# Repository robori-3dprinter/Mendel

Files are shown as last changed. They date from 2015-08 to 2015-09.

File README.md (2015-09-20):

# Robori Mendel

File master printer 3D Robori Mendel.

Full kit printer 3D Robori Mendel tersedia di :

http://www.robori.com/index.php?id_product=95&controller=product

Spesifikasi printer 3D Robori Mendel dan panduan merakit dapat dilihat di :

http://www.robori.com/documentation/Mendel

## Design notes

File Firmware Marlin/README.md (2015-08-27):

Firmware Marlin yang dikonfigurasi untuk printer 3D Robori Mendel.

Langkah-langkah meng-upload ke board Arduino Mega 2560 :
- Install Arduino versi 1.0.6 dari <a href="https://www.arduino.cc/en/Main/OldSoftwareReleases#previous">website Arduino</a>.
- Jalankan program Arduino dan buka file Marlin.ino yang terdapat di folder Marlin.
- Hubungkan board Arduino Mega ke komputer dengan kabel USB.
- Pilih menu Tools - Board - Arduino Mega 2560 or Mega ADK.
- Pilih menu Tools - Serial Port dan pilih port Arduino Mega yang didaftarkan sistem operasi saat menghubungkan board Arduino Mega ke komputer.
- Klik tombol Upload dan tunggu hingga proses compile dan upload selesai.

Firmware Marlin merupakan proyek open source dengan lisensi GPL. Versi asli dan terbaru dari firmware ini dapat didownload di :

https://github.com/MarlinFirmware

Dokumentasi firmware Marlin terdapat di :

http://www.marlinfirmware.org

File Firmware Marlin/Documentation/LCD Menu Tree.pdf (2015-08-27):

# Marlin LCD Menu Tree

Main Menu | Tune Menu | Move Menu
Info screen | Main | Prepare
Tune | Speed | Move 10mm | Move Menu
Prepare | Nozzle | Move 1mm | Move axis
Control | Nozzle2 | Move 0.1mm | Move X
Pause print | Nozzle3 | | Move Y
Resume print | Bed | | Move Z
Stop print | Fan speed | Temperature Menu | Extruder
Print from SD | Flow | Control
Change SD card | Babystep X | Nozzle
No SD card | Babystep Y | Nozzle2
Init. SD card | Babystep Z | Nozzle3
| Change filament | Bed
| | Fan speed
| | Autotemp
| Prepare Menu | \002 Min
| Main | \002 Max | Preheat PLA
| Autostart | \002 Fact | Temperature
| Disable steppers | PID-P | Fan speed
| Auto home | PID-I | Nozzle
| Preheat PLA | PID-D | Bed
| Preheat ABS | PID-C | Store memory
| Cooldown | Preheat PLA conf
| Switch power off | Preheat ABS conf | Preheat ABS
Switch power on | Temperature
Move axis | Fan speed
| Motion Menu | Nozzle
| Control | Bed
Control Menu | Z Offset | Store memory
Main | Accel
Temperature | Vxy-jerk
Motion | Vz-jerk
LCD contrast | Ve-jerk
Retract | Vmax x
Store memory | Vmax y
Load memory | Vmax z
Restore failsafe | Vmax e
| Vmin
| VTrav min
SD Card Menu | Amax x
Main | Amax y
Refresh | Amax z
filenames | Amax e
| A-retract
| Xsteps/mm
| Ysteps/mm
| Zsteps/mm
| Esteps/mm
| Endstop abort

Retract Menu
Control
AutoRetr.
Retract mm
Retract F
Hop mm
UnRet +mm
UnRet F

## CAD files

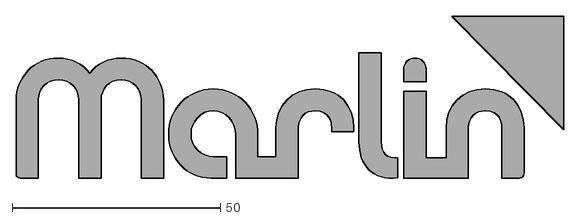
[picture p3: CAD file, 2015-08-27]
Firmware Marlin/Documentation/Logo/Marlin Logo.dxf
131.6 x 39.5

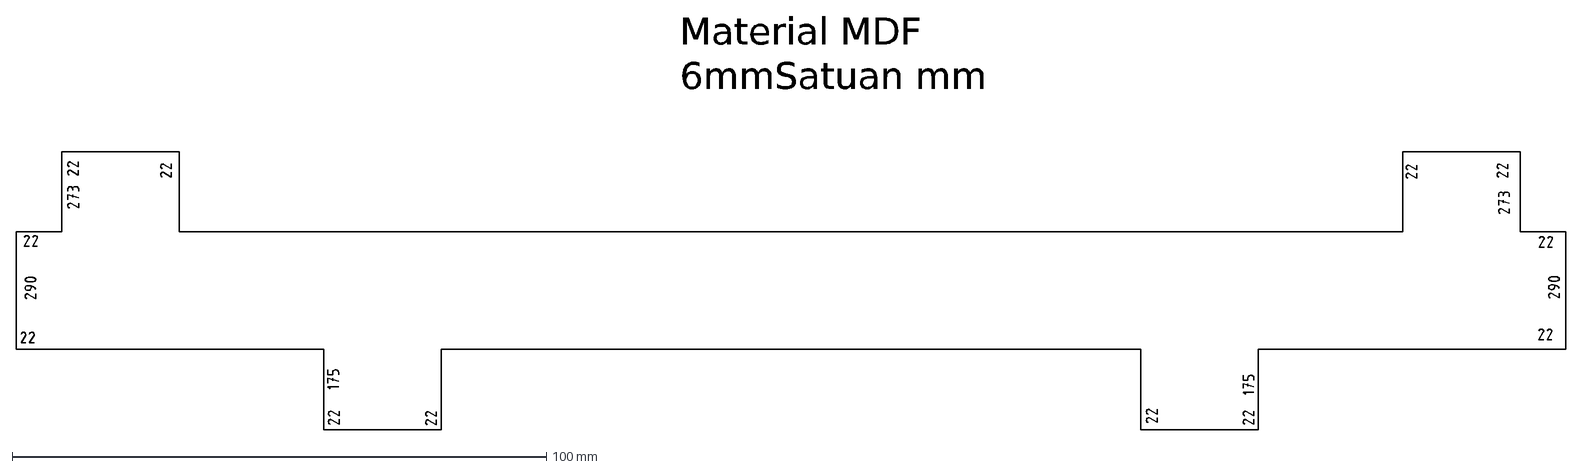
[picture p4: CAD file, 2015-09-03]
Lasercut Part/measuring-jig.dxf
Material MDF 6mm Satuan mm

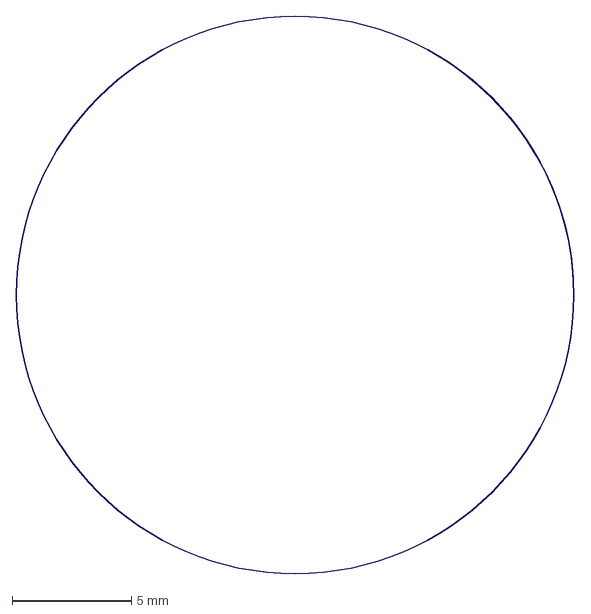
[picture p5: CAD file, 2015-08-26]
OpenSCAD/vertex-body-hole-qcad.dxf
23.4 x 23.4 mm

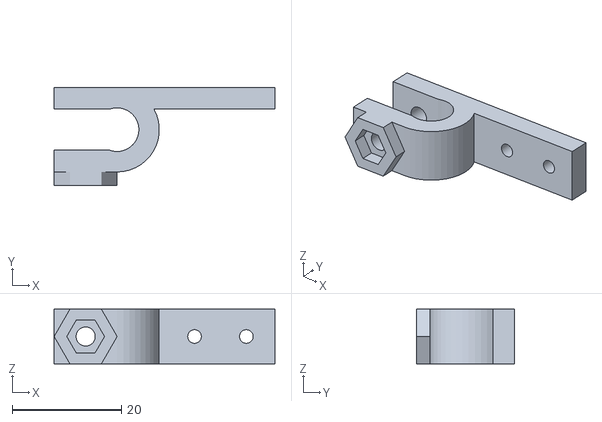
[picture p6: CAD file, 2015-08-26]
Printed Part/endstop-holder-3x.stl
40.5 x 18.0 x 10.0

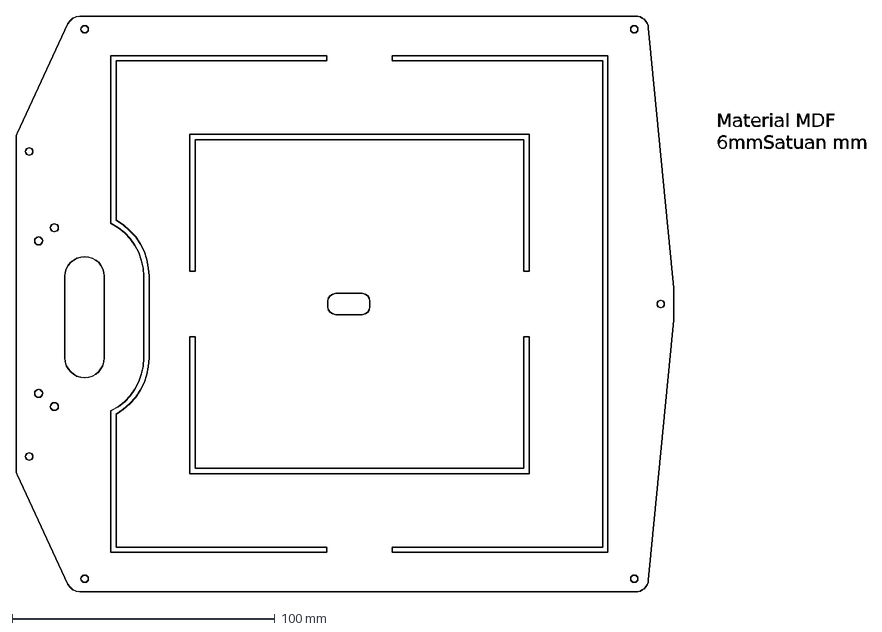
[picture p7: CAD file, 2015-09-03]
Lasercut Part/heat-bed-insulator.dxf
Material MDF 6mm Satuan mm

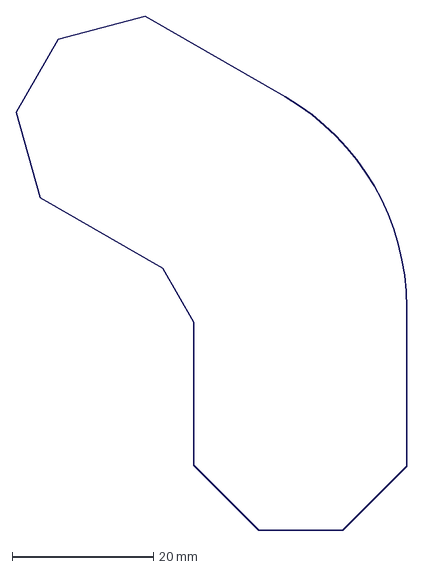
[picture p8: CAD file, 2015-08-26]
OpenSCAD/vertex-body-fixed-qcad.dxf
55.4 x 72.9 mm

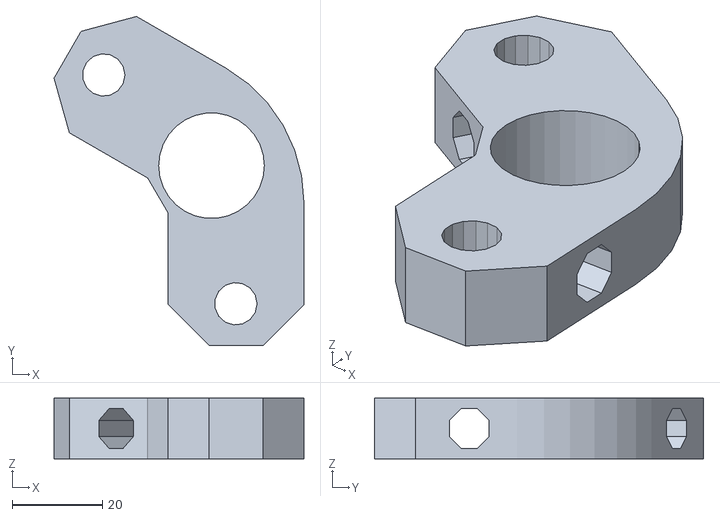
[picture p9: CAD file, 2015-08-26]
Printed Part/frame-vertex-2x.stl
55.4 x 72.9 x 13.5

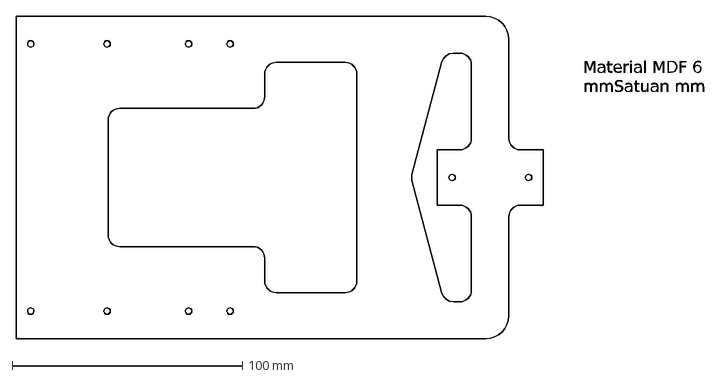
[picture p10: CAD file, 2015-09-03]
Lasercut Part/y-carriage.dxf
Material MDF 6 mm Satuan mm

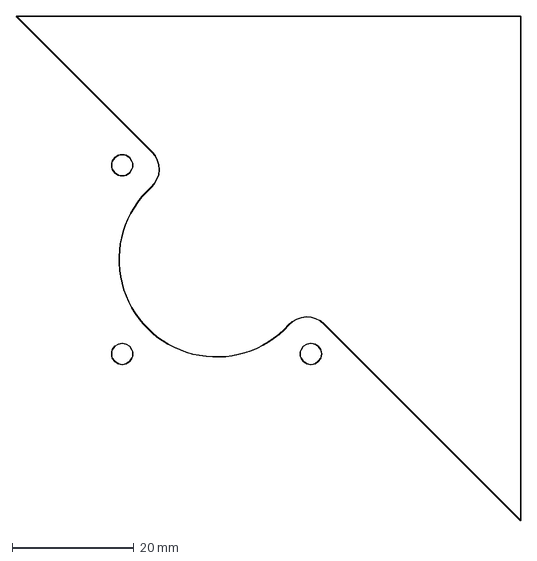
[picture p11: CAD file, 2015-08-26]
OpenSCAD/x-motor-cutout.dxf
82.9 x 82.9 mm

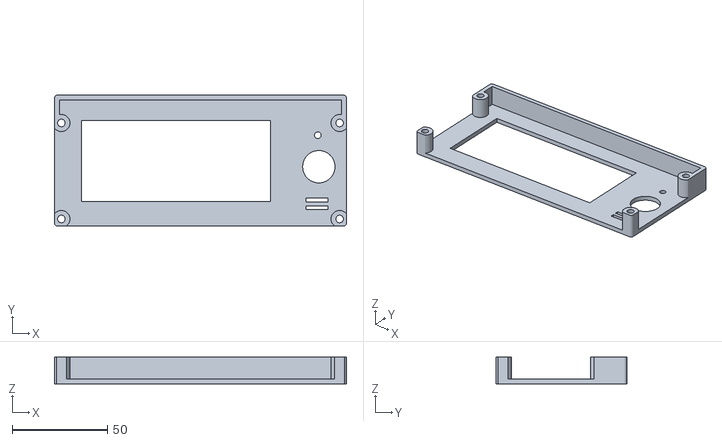
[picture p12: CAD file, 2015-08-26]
Printed Part/lcd-cover-1x.stl
153.0 x 68.5 x 14.0

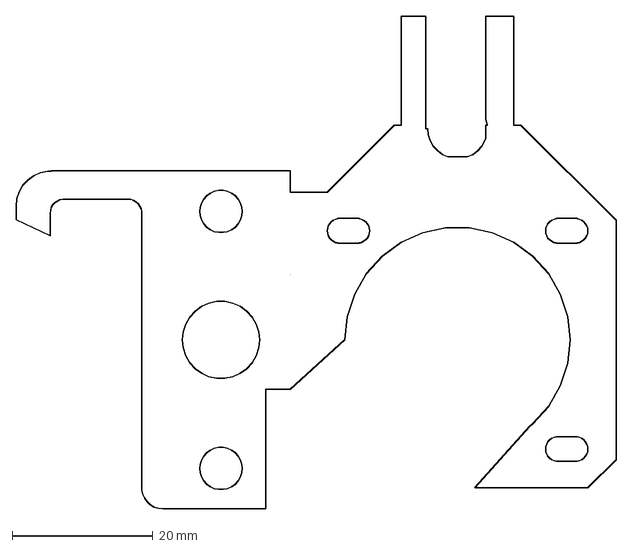
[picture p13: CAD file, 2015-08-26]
OpenSCAD/extruder-block-projection.dxf
85.2 x 70.0 mm

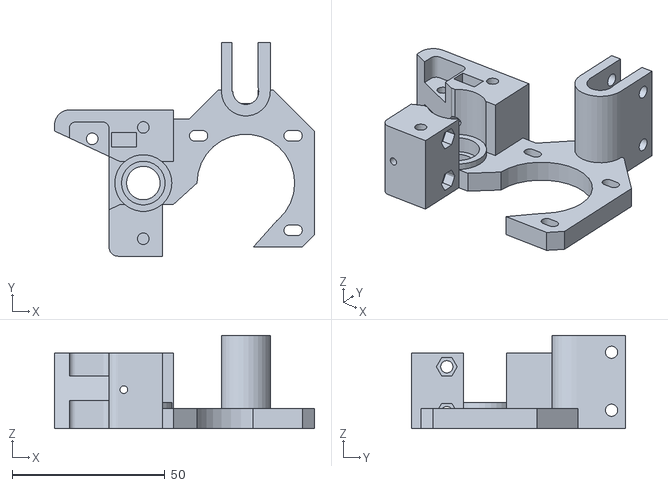
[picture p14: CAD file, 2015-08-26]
Printed Part/extruder-block-1x.stl
85.2 x 70.0 x 30.5

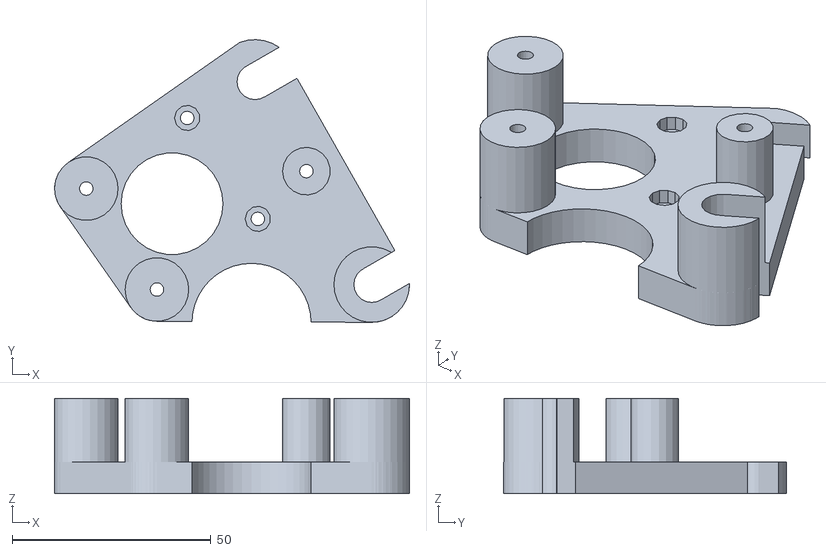
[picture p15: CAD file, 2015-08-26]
OpenSCAD/reprappro-y-motor-mount-1off.stl
89.3 x 71.2 x 24.0

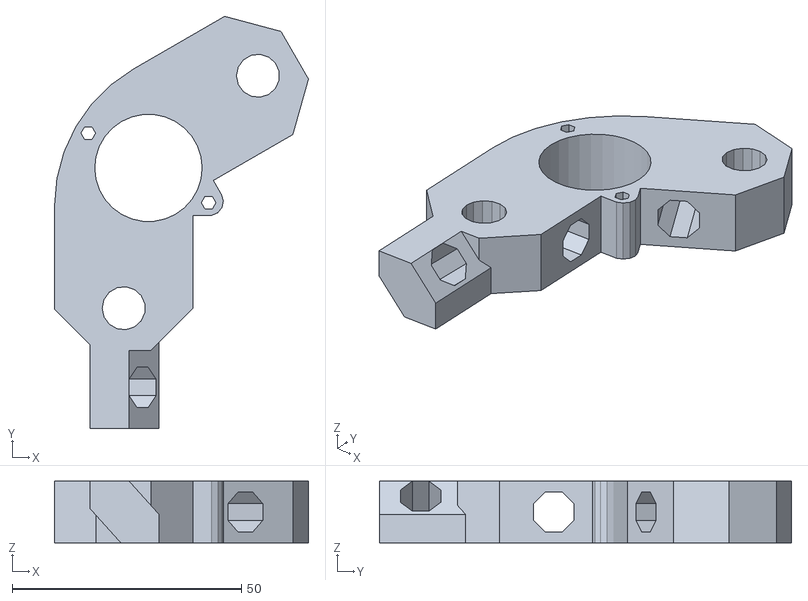
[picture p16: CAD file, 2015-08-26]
Printed Part/frame-vertex-foot-right-2x.stl
55.4 x 89.9 x 13.5

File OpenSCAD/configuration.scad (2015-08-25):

// PRUSA Mendel  
// Configuration file
// GNU GPL v2
// Josef Pra
// josefprusa@me.com
// prusadjs.cz
// http://www.reprap.org/wiki/Prusa_Mendel
// http://github.com/prusajr/PrusaMendel


// PLEASE SELECT ONE OF THE CONFIGURATIONS BELOW
// BY UN-COMMENTING IT


variant=0; //0 for metric
//variant=1; //1 for SAE
if(variant==0){
echo("variant: metric");
}else if(variant==1){
echo("variant: sae");
} else{
echo("WARNING: INVALID CONFIGURATION");
}




vars=[
//[m8_dia,m8_nut, m4_dia, m4_nut, m3_dia, m3_nut, bush_dia, mot_shaft, bush_rod, bush_outerdia, bush_length, m5_dia, m5_nut]
[9, 16.4, 5,9, 3.4, 6.5, 11, 5.3, 8, 16, 11, 5.6, 10],//metric - M3 nut was 7; M3 was 4.4
[9,15.7,5.5,10.6,5.5,10.6,11.5,5.3,7.9375,16,11,5.6, 10]//SAE
];


//BUSHING TYPE Can generate three versions
// 1 - regular old ones
// 2 - helical ones
// 3 - holders for brass or any other bought bushings
bushing_type = 2;


//Round corner diameter
round_corner_diameter = 5;		// Original = 8


//Thin wall size
layer_height = 0.4;
perimeter_width_over_thicknes = 1.6;
infill_widht_over_thickness = 1.55;
thin_wall = 2*(perimeter_width_over_thicknes*layer_height+infill_widht_over_thickness*layer_height);
if(thin_wall<2){
	echo("Check thin wall size, its below 2mm!");
}
echo(thin_wall);


//DO NOT TOUCH THIS SECTION!
m8_diameter = vars[variant][0];
m8_nut_diameter = vars[variant][1];
m4_diameter = vars[variant][2];
m4_nut_diameter = vars[variant][3];
m3_diameter = vars[variant][4];
m3_nut_diameter = vars[variant][5];
bushing_diameter = vars[variant][6];
motor_shaft=vars[variant][7];
bushing_rodsize = vars[variant][8];
bushing_outerDiameter = vars[variant][9];
bushing_lenght = vars[variant][10];
m5_diameter = vars[variant][11];
m5_nut_diameter = vars[variant][12];



// MINI-HUXLEY VERSION (TODO, just place holder)
// include <configuration-huxley.scad>


// MEGA VERSION (TODO, just place holder)
// include <configuration-mega.scad>

// Robori Mendel
include <x-axis-data.scad>

// Gap between the X rods

//x_rod_centres=70;			// Prusa Mendel
x_rod_centres=rod_dist;		// Robori Mendel
y_rod_centres=183;
belt_width=6;
belt_clamp_centres=18;
ptfe_diameter=4;
z_slot_width=3.5;

vertex_x_rod_1=[11.013,59.912];
vertex_x_rod_2=[40.274,9.249,0];
vertex_x_rod_gap=sqrt((vertex_x_rod_1.x-vertex_x_rod_2.x)*(vertex_x_rod_1.x-vertex_x_rod_2.x) +(vertex_x_rod_1.y-vertex_x_rod_2.y)*(vertex_x_rod_1.y-vertex_x_rod_2.y) );

// Some basic functions, probably should be somewhere else
module roundcorner(diameter){
	difference(){
		cube(size = [diameter,diameter,99], center = false);
		translate(v = [diameter, diameter, 0]) cylinder(h = 100, r=diameter, center=true);
	}
}

include <functions.scad>

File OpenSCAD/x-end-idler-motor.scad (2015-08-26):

// PRUSA Mendel  
// X-end with idler mount
// GNU GPL v2
// Josef Pra
// josefprusa@me.com
// prusadjs.cz
// http://www.reprap.org/wiki/Prusa_Mendel
// http://github.com/prusajr/PrusaMendel

include <configuration.scad>
include <bearing-mount-include.scad>
include <library/library_3d.scad>

lib3d_fn = 25;
$fn = 25;

// Modified by Adrian to remove bridges and to add a conical cavity for the bottom nut; this
// prints more cleanly and reliably.  26 May 2011

// Modified by Adrian to use an M5 nut drive, linear bearings, friction clamps rather than screw clamps, 
// And to generate both the motor and idler ends
// 9 Feb 2012

// 30 Jan 2015
// Modified by Neuro (Robori.com)
// - Prusa i3 style LM8UU bearing holder
// - New idler bearing holder with M5 screw hole for 605 bearing
// - Change rod centers to 65mm (default 70mm)
// - Make bigger void

// Print 1 of the objects generated when this is true, and one when it is false.
motor=true;

// Set this false for Igus bearings, true for LM8UUs
lm8uu=true;

// Show / hide rod centers
scaffold=false;

corection = 1.17; 
back_clamp=[-x_rod_centres/2, -5, 0];
front_clamp=[x_rod_centres/2, -5, 0];
z_adjust_radius=21;		// Original = 31.6
z_adjust_angle=80;			// Original = 45


module clamp()
{
	translate(v=[1, 0, 9]) difference()
	{
		translate(v=[1, 0, -3.5]) cube(size=[10, 29, 7], center=true);
		rotate([90, 0, 0]) cylinder(h=38, r=m8_diameter/2, $fn=20, center=true);
		translate([-1, -15, 0.5]) rotate([30, 0, 0]) cube([20, 20, 10], center=true);
		translate([-1, 15, 0.5]) rotate([-30, 0, 0]) cube([20, 20, 10], center=true);
	}
}

module clamp_gap()
{
	difference()
	{
		translate(v=[0, 0, 0]) cube(size=[6, 30, 15], center=true);
		translate(v=[1, 0, 0]) cube(size=[6, 28, 20], center=true);
	}
}

module xend_i()
{
	difference()
	{
		union()
		{
			if(motor)
			{
				// Block the ends
				translate(v = [-x_rod_centres/2+0.5, 13, 8])cube(size = [10,4,13], center = true);
				translate(v = [x_rod_centres/2-0.5, 13, 8])cube(size = [10,4,13], center = true);
			}
			else
			{
				// End adjust
				difference()
				{
					union()
					{
						translate(v = [-x_rod_centres/2, 18, 6.5])cube(size = [17,14,13], center = true);
						translate(v = [x_rod_centres/2, 18, 6.5])cube(size = [17,14,13], center = true);
					}
					translate(v = [-x_rod_centres/2, 13, 6.5])cube(size = [9,14,23], center = true);
					translate(v = [x_rod_centres/2, 13, 6.5])cube(size = [9,14,23], center = true);
					//Adjustment screws
					translate(v = [-x_rod_centres/2, 35, -16.7+24.5]) rotate(a=[90,0,0]) 
					{
						translate(v = [0, 0, 22]) cylinder(h = 42, r=1.7, $fn=20, center=true);
						translate(v = [0, 0, 17]) rotate(a=[0,0,30]) cylinder(h = 8, r=m3_nut_diameter/2, $fn=6, center=true);
					}
					translate(v = [x_rod_centres/2, 35, -16.7+24.5]) rotate(a=[90,0,0]) 
					{
						translate(v = [0, 0, 22]) cylinder(h = 42, r=1.5, $fn=20, center=true);
						translate(v = [0, 0, 17])   rotate(a=[0,0,30]) cylinder(h = 8, r=m3_nut_diameter/2, $fn=6, center=true);
					}
				}
			}

			// Rod centers
			if(scaffold)
			{
				translate(v = [0, -20, 0]) cylinder(h = 100, r=1, $fn=10, center=true);// Centre-marker screw drive
				translate(v = [0, 10, 0])cylinder(h = 100, r=1, $fn=30, center=true);// Centre-marker bearings
			}

			// The x rod clamps
			translate(back_clamp) clamp();
			translate(front_clamp) mirror([1,0,0]) clamp();

			difference()
			{
				translate(v = [0,35,24.5]) union()
				{
					difference()
					{
						// Rod block
						union()
						{
							translate(v = [-x_rod_centres/2+5, -40, -16.6])cube(size = [x_rod_centres/2-5,40,15.8], center = true);
							translate(v = [x_rod_centres/2-5, -40, -16.6])cube(size = [x_rod_centres/2-5,40,15.8], center = true);
						}
			
						//round corners
						translate(v = [x_rod_centres/2 + 10.1 - 1, -60.1, -25]) rotate(a=[0,0,90]) roundcorner(round_corner_diameter);
						translate(v = [x_rod_centres/2 + 10.1 - 1, -19.9, -25]) rotate(a=[0,0,-180]) roundcorner(round_corner_diameter);

						//holes for X axis
						translate(v = [-x_rod_centres/2, -18, -16.7]) rotate(a=[90,0,0])
						{
							translate(v = [0, 0, 22]) cylinder(h = 42, r=4.5, $fn=20, center=true);
							translate(v = [0, 2.60, 22]) rotate(a=[0,0,0]) cylinder(h = 42, r=3.65, $fn=6, center=true);
						}
						translate(v = [x_rod_centres/2, -18, -16.7]) rotate(a=[90,0,0])
						{
							translate(v = [0, 0, 22]) cylinder(h = 42, r=4.5, $fn=20, center=true);
							translate(v = [0, 2.60, 22]) rotate(a=[0,0,0]) cylinder(h = 42, r=3.65, $fn=6, center=true);
						}
			
						//slider cutouts --> ??
						translate(v = [0, -25, 15]) difference()
						{
							translate(v = [0, -0, -14.5])cube(size = [23,23,50], center = true);
						}
			
						//nut trap --> ??
						translate(v = [0, -55, 15])
						{
							difference()
							{
								translate(v = [0, -0, -15])cylinder(h = 50, r=m8_nut_diameter/2+thin_wall, $fn=6, center=true);
							}
						}
					}
			
					translate(v = [0, -25, 15]) difference()
					{
						union()
						{
							if(lm8uu)
							{
								// Disabled : replaced with Prusa i3 style LM8UU holder
								//translate(v = [0, -8, -7]) cube(size = [17+2*thin_wall,8, 65], center = true);
							}
							else
							{
								translate(v = [0, -8, -7]) cube(size = [17+2*thin_wall,8, 39], center = true);
							}
							translate(v = [0, -3.5, -31.6]) cube(size = [33,17,15.8], center = true);
						}
						translate(v = [0, 0, -17]) cube(size = [17,17, 105], center = true);
						translate(v = [0, 5, -31.6]) cube(size = [24,17,20], center = true);
					}
			
					// Bearing holders
					if(lm8uu)
					{
						// Disabled : replaced with Prusa i3 style LM8UU holder
						//translate([0,-34.5,-12.5]) rotate([-90,0,0]) bearing_holder(with_mountplate=false, vertical=true, slope=false,igus=!lm8uu);
						//translate([0,-34.5,28.5]) rotate([-90,0,0]) bearing_holder(with_mountplate=false, vertical=true, slope=true,igus=!lm8uu);
						// Prusa i3 LM8UU holder
						translate([0, -35 + 10, -24.5]) rotate([0, 0, 180]) prusa_i3_bearing_holder();
					}
					else
					{
						difference()
						{
							translate([0,-34.5,-24]) rotate([-90,0,0]) bearing_holder(with_mountplate=false, vertical=true, slope=false,igus=!lm8uu);
							translate([0,0,-49.5]) cube([100,100,50],center=true);
						}
						translate([0,-34.5,15.5]) rotate([-90,0,0]) bearing_holder(with_mountplate=false, vertical=true, slope=true,igus=!lm8uu);
					}
			
					//nut trap
					//correction for thin wall
					translate(v = [0, -55, 15])
					{
						difference()
						{
							union()
							{
								difference()
								{
									union()
									{
										translate(v = [0, -0, -19.5]) cylinder(h = 40, r=m5_nut_diameter/2+thin_wall*corection, $fn=6, center=true);
										translate(v = [0, 0, -31.6]) cube(size = [35,10,15.8], center = true);
									}
									cylinder(h = 90, r=m5_nut_diameter/2, $fn=6, center=true);
								}
					
								// Generate nut barrier with conical lead in under. 
								difference()
								{
									translate(v = [0, 0, -29]) cylinder(h = 16, r=m5_nut_diameter/2+thin_wall, $fn=6, center=true);
									translate(v = [0, 0, -32]) cylinder(h = 10, r1=10+2.5, r2=2.5, $fn=30, center=true);
									cylinder(h = 100, r=2.75, $fn=30, center=true);
								}
							}
							translate(v = [0, 0, 12.5]) cylinder(h = 90, r=m5_diameter/2, $fn=9, center=true);
						}
					}
			
					if(motor)
					{
						// Motor connector
						// x = motor body, y = motor center, z = motor center
						translate([0, -35, -24.5]) translate([-rod_dist/2 - belt_rod_dist + 0.75 + PULLEY_GT2_FLANGE_L + 5.5, 19.5 + 5 + NEMA17_L/2, 7.8 + belt_rod_h + 1.38 + PULLEY_GT2_TEETH_OD/2]) difference()
						{
							union()
							{
								translate([-6, -NEMA17_L/2 - 10, -NEMA17_L/2 - 5.68]) cube([6, NEMA17_L + 10, NEMA17_L + 5.68]);
								translate([-6, -30.5 - 4, -11.5]) cube([23.25 + 6, 4, 32.5]);
							}
							rotate([0,0,90]) rotate([90,0,0]) linear_extrude(file = "x-motor-cutout.dxf", layer = "0", height = 20, center = true, convexity = 10, twist = 0);
							translate([23.25, -30.5 - 6 - 1, -11.5 + 0.63]) rotate([0, -30, 0]) cube([30, 6 + 2, 40]);
						}
						/*** Disabled : Old motor connector
						difference()
						{
							//nema17 connector
							translate(v = [0, 3, -12]) mirror([1,0,0]) difference()
							{
								union()
								{
									translate(v = [x_rod_centres/2-4, -24.0, 20.5]) difference()
									{
										cube(size = [24,2,38], center = true); // Changed to a web
										translate(v = [-20, 0, 0]) rotate([0,15,0]) cube(size = [34,8,55], center = true);
									}
									translate(v = [x_rod_centres/2 + 7.5, 2, 13.5]) cube(size = [5,54,52], center = true);
									translate(v = [x_rod_centres/2 - 2.5, 2, -11]) cube(size = [20,54,3], center = true);
								}
								
								// some reduction of bottom part
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

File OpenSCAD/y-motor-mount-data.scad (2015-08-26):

// ========================================================================================
// Robori Mendel
// Shared modules for Y motor mount parts
// GNU GPL v3
//
// Contact : support@robori.com
// Reference : http://www.robori.com/documentation/Mendel
//
// History :
// 28 Jan 2015 - First version
// ========================================================================================

module belt_guide_bushing()
{
	// 2015-05-17 : increase height by 0.25mm
	linear_extrude(height=1 + 0.25 + 0.25, center=false, convexity=10) import(file="../dxf/y-motor-mount.dxf", layer="belt-guide-bushing-profile");
}

module bearing_bushing()
{
	bb_h = 3 + 0.25;
	bb_id = 5 + 0.5;
	bb_od1 = bb_id + 2*3;
	bb_od2 = bb_id + 2*1.5;
	
	difference()
	{
		cylinder(h=bb_h, r1=bb_od1/2, r2=bb_od2/2, center=false);
		translate([0, 0, -1]) cylinder(h=bb_h + 2, r=bb_id/2, center=false);
	}
}

// base h = 5
// bushing h = 16
module y_motor_mount_base()
{
	idler_d = 5 + 0.5;

	translate([0, 0, -3]) difference()
	{
		union()
		{
			// Original :
			//   base h = 8
			//   bushing h = 16
			import("reprappro-y-motor-mount-1off.stl");
			// Fill screw holes
			translate([-7, -25, 3]) cube([6, 6, 5]);
			translate([0, 17, 3]) cube([10, 10, 5]);
			translate([17, -8, 3]) cube([10, 10, 5]);
			translate([31, 5, 3]) cube([6, 6, 5]);
		}
		// Base h = 5
		translate([-35, -35, -1]) cube([100, 80, 3 + 1]);
		// Remove bushings
		translate([-30, -5, 8]) cube([20, 20, 16 + 1]);
		translate([-12, -30, 8]) cube([20, 20, 16 + 1]);
		translate([20, 0, 8]) cube([20, 20, 16 + 1]);
		// Motor screw slots
		translate([21.59, -3.81, 3 - 1]) rotate([0, 0, 53.77]) motor_screw_slot();
		translate([-21.59, 3.81, 3 - 1]) rotate([0, 0, 53.77]) motor_screw_slot();
		// Idler bearing screw hole
		translate([30.83, 10.02, 3 - 1]) cylinder(h=5 + 2, r=idler_d/2, center=false);
	}
}

module motor_screw_slot()
{
	base_h = 5;
	d = 3 + 0.5;
	l = 7;
	x = l/2 - d/2;

	union()
	{
		translate([-x, -d/2, 0]) cube([l - d, d, base_h + 2]);
		translate([x, 0, 0]) cylinder(h=base_h + 2, r=d/2, center=false);
		translate([-x, 0, 0]) cylinder(h=base_h + 2, r=d/2, center=false);
	}
}

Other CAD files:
OpenSCAD/prusa-i3-x-idler-1.stl
Printed Part/extruder-tongue-1x.stl
OpenSCAD/vertex-body-hole-foot.dxf
Printed Part/x-end-idler-1x.stl
OpenSCAD/y-motor-mount-plate.scad
OpenSCAD/bearing-mount-include.scad
OpenSCAD/endstop-holder.scad
OpenSCAD/extruder-bearing-cover.scad
OpenSCAD/extruder-block.scad
OpenSCAD/extruder-large-gear.scad
OpenSCAD/extruder-retainer.scad
OpenSCAD/extruder-small-gear.scad
OpenSCAD/extruder-tongue.scad
OpenSCAD/filament-holder-clamp-front.scad
OpenSCAD/filament-holder-clamp-rear.scad
OpenSCAD/filament-holder-end.scad
OpenSCAD/frame-vertex-readme.scad
OpenSCAD/functions.scad
OpenSCAD/lcd-clamp.scad
OpenSCAD/lcd-cover.scad
OpenSCAD/pcb-clamp-bottom.scad
OpenSCAD/pcb-clamp-corner.scad
OpenSCAD/pcb-clamp-data.scad
OpenSCAD/pcb-clamp-top.scad
OpenSCAD/pcb-fan-holder.scad
OpenSCAD/prusa-i3-endstop-holder-3.stl
OpenSCAD/psu-cover.scad
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

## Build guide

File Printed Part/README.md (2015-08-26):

Jumlah printing tiap part ditunjukkan oleh angka di belakang nama file, contohnya bar-clamp-8x.stl berarti dibutuhkan 8 buah bar clamp untuk 1 unit printer.

File printed part telah diuji printing dan rakit dengan tinggi layer 0,3mm dan tidak memerlukan support. Bahan printed part menggunakan PLA kecuali untuk part berikut :

(1) extruder-block dan extruder-retainer menggunakan ABS

(2) x-carriage dan y-belt-clamp menggunakan ABS apabila printer akan digunakan untuk printing ABS, untuk printing PLA cukup dari bahan PLA

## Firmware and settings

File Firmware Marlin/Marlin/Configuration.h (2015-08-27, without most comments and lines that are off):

#define CONFIGURATION_H
#include "boards.h"
#define STRING_VERSION_CONFIG_H __DATE__ " " __TIME__ // build date and time
#define STRING_CONFIG_H_AUTHOR "Robori" // Who made the changes.
#define SERIAL_PORT 0
#define BAUDRATE 250000
  #define MOTHERBOARD BOARD_RAMPS_13_EFB
#define CUSTOM_MENDEL_NAME "Robori Mendel"
#define EXTRUDERS 1
#define POWER_SUPPLY 1
#define TEMP_SENSOR_0 10
#define TEMP_SENSOR_1 0
#define TEMP_SENSOR_2 0
#define TEMP_SENSOR_BED 40
#define MAX_REDUNDANT_TEMP_SENSOR_DIFF 10
#define TEMP_RESIDENCY_TIME 10  // (seconds)
#define TEMP_HYSTERESIS 3       // (degC) range of +/- temperatures considered "close" to the target one
#define TEMP_WINDOW     1       // (degC) Window around target to start the residency timer x degC early.
#define HEATER_0_MINTEMP 5
#define HEATER_1_MINTEMP 5
#define HEATER_2_MINTEMP 5
#define BED_MINTEMP 5
#define HEATER_0_MAXTEMP 300
#define HEATER_1_MAXTEMP 300
#define HEATER_2_MAXTEMP 300
#define BED_MAXTEMP 130
#define PIDTEMP
#define BANG_MAX 255 // limits current to nozzle while in bang-bang mode; 255=full current
#define PID_MAX BANG_MAX // limits current to nozzle while PID is active (see PID_FUNCTIONAL_RANGE below); 255=full current
  #define PID_FUNCTIONAL_RANGE 10 // If the temperature difference between the target temperature and the actual temperature
  #define PID_INTEGRAL_DRIVE_MAX PID_MAX  //limit for the integral term
  #define K1 0.95 //smoothing factor within the PID
  #define PID_dT ((OVERSAMPLENR * 10.0)/(F_CPU / 64.0 / 256.0)) //sampling period of the temperature routine
    #define  DEFAULT_Kp 17.57
    #define  DEFAULT_Ki 2.03
    #define  DEFAULT_Kd 38.01
#define MAX_BED_POWER 255 // limits duty cycle to bed; 255=full current
#define PREVENT_DANGEROUS_EXTRUDE
#define PREVENT_LENGTHY_EXTRUDE
#define EXTRUDE_MINTEMP 170
#define EXTRUDE_MAXLENGTH (X_MAX_LENGTH+Y_MAX_LENGTH) //prevent extrusion of very large distances.
#define ENDSTOPPULLUPS // Comment this out (using // at the start of the line) to disable the endstop pullup resistors
  #define ENDSTOPPULLUP_XMAX
  #define ENDSTOPPULLUP_YMAX
  #define ENDSTOPPULLUP_ZMAX
  #define ENDSTOPPULLUP_XMIN
  #define ENDSTOPPULLUP_YMIN
  #define ENDSTOPPULLUP_ZMIN
const bool X_MIN_ENDSTOP_INVERTING = false; // set to true to invert the logic of the endstop.
const bool Y_MIN_ENDSTOP_INVERTING = false; // set to true to invert the logic of the endstop.
const bool Z_MIN_ENDSTOP_INVERTING = false; // set to true to invert the logic of the endstop.
const bool X_MAX_ENDSTOP_INVERTING = false; // set to true to invert the logic of the endstop.
const bool Y_MAX_ENDSTOP_INVERTING = false; // set to true to invert the logic of the endstop.
const bool Z_MAX_ENDSTOP_INVERTING = false; // set to true to invert the logic of the endstop.
#define DISABLE_MAX_ENDSTOPS
#if defined(COREXY) && !defined(DISABLE_MAX_ENDSTOPS)
  #define DISABLE_MAX_ENDSTOPS
#endif
#define X_ENABLE_ON 0
#define Y_ENABLE_ON 0
#define Z_ENABLE_ON 0
#define E_ENABLE_ON 0 // For all extruders
#define DISABLE_X false
#define DISABLE_Y false
#define DISABLE_Z false
#define DISABLE_E false // For all extruders
#define DISABLE_INACTIVE_EXTRUDER true //disable only inactive extruders and keep active extruder enabled
#define INVERT_X_DIR false    // for Mendel set to false, for Orca set to true
#define INVERT_Y_DIR false    // for Mendel set to true, for Orca set to false
#define INVERT_Z_DIR true     // for Mendel set to false, for Orca set to true
#define INVERT_E0_DIR false   // for direct drive extruder v9 set to true, for geared extruder set to false
#define INVERT_E1_DIR false    // for direct drive extruder v9 set to true, for geared extruder set to false
#define INVERT_E2_DIR false   // for direct drive extruder v9 set to true, for geared extruder set to false
#define X_HOME_DIR -1
#define Y_HOME_DIR -1
#define Z_HOME_DIR -1
#define min_software_endstops true // If true, axis won't move to coordinates less than HOME_POS.
#define max_software_endstops true  // If true, axis won't move to coordinates greater than the defined lengths below.
#define X_MAX_POS 190
#define X_MIN_POS 0
#define Y_MAX_POS 200
#define Y_MIN_POS 0
#define Z_MAX_POS 125
#define Z_MIN_POS 0
#define X_MAX_LENGTH (X_MAX_POS - X_MIN_POS)
#define Y_MAX_LENGTH (Y_MAX_POS - Y_MIN_POS)
#define Z_MAX_LENGTH (Z_MAX_POS - Z_MIN_POS)
#define Z_PROBE_REPEATABILITY_TEST  // If not commented out, Z-Probe Repeatability test will be included if Auto Bed Leveling is Enabled.
#define MANUAL_X_HOME_POS 0
#define MANUAL_Y_HOME_POS 0
#define MANUAL_Z_HOME_POS 0
#define NUM_AXIS 4 // The axis order in all axis related arrays is X, Y, Z, E
#define HOMING_FEEDRATE {40*60, 40*60, 2*60, 0}  // set the homing speeds (mm/min)
#define DEFAULT_AXIS_STEPS_PER_UNIT   {80, 80, 4000, 414.7}
#define DEFAULT_MAX_FEEDRATE          {300, 300, 3, 45}    // (mm/sec)
#define DEFAULT_MAX_ACCELERATION      {800, 800, 30, 250}    // X, Y, Z, E maximum start speed for accelerated moves. E default values are good for Skeinforge 40+, for older versions raise them a lot.
#define DEFAULT_ACCELERATION          1000    // X, Y, Z and E max acceleration in mm/s^2 for printing moves
#define DEFAULT_RETRACT_ACCELERATION  1000   // X, Y, Z and E max acceleration in mm/s^2 for retracts
#define DEFAULT_XYJERK                15.0    // (mm/sec)
#define DEFAULT_ZJERK                 0.4     // (mm/sec)
#define DEFAULT_EJERK                 15.0    // (mm/sec)
#define CUSTOM_M_CODES
  #define CUSTOM_M_CODE_SET_Z_PROBE_OFFSET 851
  #define Z_PROBE_OFFSET_RANGE_MIN -15
  #define Z_PROBE_OFFSET_RANGE_MAX -5
#define EEPROM_SETTINGS
#define EEPROM_CHITCHAT
#define PLA_PREHEAT_HOTEND_TEMP 210
#define PLA_PREHEAT_HPB_TEMP 65
#define PLA_PREHEAT_FAN_SPEED 0   // Insert Value between 0 and 255
#define ABS_PREHEAT_HOTEND_TEMP 250
#define ABS_PREHEAT_HPB_TEMP 100
#define ABS_PREHEAT_FAN_SPEED 0   // Insert Value between 0 and 255
#define REPRAP_DISCOUNT_SMART_CONTROLLER
 #define ULTIPANEL
 #define NEWPANEL
  #define SDSUPPORT
  #define ULTRA_LCD
    #define LCD_WIDTH 20
    #define LCD_HEIGHT 4
#define SOFT_PWM_SCALE 0
#define FILAMENT_SENSOR_EXTRUDER_NUM	0  //The number of the extruder that has the filament sensor (0,1,2)
#define MEASUREMENT_DELAY_CM			14  //measurement delay in cm.  This is the distance from filament sensor to middle of barrel
#define DEFAULT_NOMINAL_FILAMENT_DIA  3.0  //Enter the diameter (in mm) of the filament generally used (3.0 mm or 1.75 mm) - this is then used in the slicer software.  Used for sensor reading validation
#define MEASURED_UPPER_LIMIT          3.30  //upper limit factor used for sensor reading validation in mm
#define MEASURED_LOWER_LIMIT          1.90  //lower limit factor for sensor reading validation in mm
#define MAX_MEASUREMENT_DELAY			20  //delay buffer size in bytes (1 byte = 1cm)- limits maximum measurement delay allowable (must be larger than MEASUREMENT_DELAY_CM  and lower number saves RAM)
#define DEFAULT_MEASURED_FILAMENT_DIA  DEFAULT_NOMINAL_FILAMENT_DIA  //set measured to nominal initially
#include "Configuration_adv.h"
#include "thermistortables.h"

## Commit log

2015-08-23 Add printed part 3D files
    [bar-clamp-8x.stl, endstop-holder-3x.stl, extruder-bearing-cover-1x.stl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]
2015-08-23 Tambah link panduan merakit dan informasi printing file 3D
2015-08-27 Update informasi firmware Marlin
2015-09-03 Add lasercut parts
    [heat-bed-insulator.dxf, measuring-jig.dxf, y-carriage.dxf]
2016-01-27 Update slicer profiles for 0.3mm and 0.5mm nozzles
